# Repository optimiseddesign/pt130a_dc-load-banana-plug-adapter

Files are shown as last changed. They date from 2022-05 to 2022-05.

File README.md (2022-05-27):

# Release Notes

This document gives information and history for the following PCB release:

|Item |Value |
|---|---|
|Board Name |DC Load Banana Plug Adapter |
|PCB ID |PT130A |
|Revision (Layout/PCB) |1.0 |
|Revision (Schematic/BOM) |1A |
|Release Date |2022-05-27 |
|Customer |Internal |

> Note: This PCB release has been designed by Optimised Product Design Ltd, on behalf of the Customer Company.

## PCB Images

Top View:

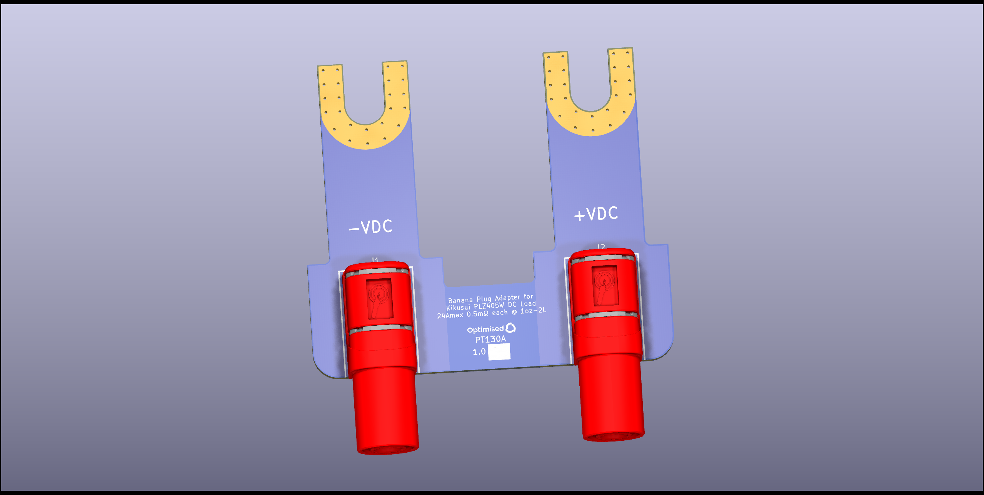
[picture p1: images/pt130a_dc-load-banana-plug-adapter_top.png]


Bottom View:

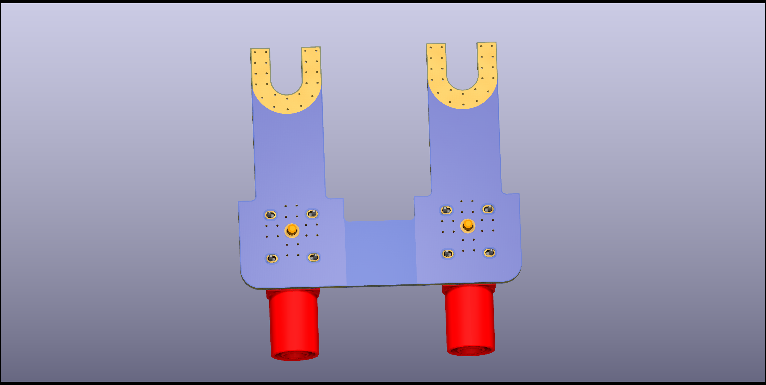
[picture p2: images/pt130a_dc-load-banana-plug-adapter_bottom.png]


[image_top]: images/pt130a_dc-load-banana-plug-adapter_top.png "Top View"
[image_bottom]: images/pt130a_dc-load-banana-plug-adapter_bottom.png "Bottom View"

## PCB Description

Adapter board for Kikusui 5W series DC Electronic Load (or similar, designed for PLZ405W).
Adapts screw terminals to shrouded sockets for 4mm Banana Plugs
24A Max, using 2-layer 1oz PCB

## Release History

```
Kevin Bibby / Optimised Product Design Ltd
PT130A 1.0 1A
27/05/2022
-------------
First release, for prototype manufacture
```

## PCB TO-DO List

The following items are to be done in future for this PCB:

**Major**
- Item

**Minor**
- Item

## Links

- [Kevin Bibby / Optimised Product Design Ltd]( http://www.optimiseddesign.com )

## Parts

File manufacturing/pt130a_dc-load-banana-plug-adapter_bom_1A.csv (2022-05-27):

Component | References | Quantity Per PCB | FitPart | Value | Description | Manufacturer1 | MPN1 | Manufacturer2 | MPN2 | Vendor1 | SKU1 | Vendor2 | SKU2
1 | J2 | 1 |  | SWEB 8094 AU / RT | RED Banana Test Connector, Jack, PCB Mount, 24 A, 1 kV | Schutzinger | SWEB 8094 AU / RT |  |  | Farnell | 3224813
2 | J1 | 1 |  | SWEB 8094 AU / SW | BLACK Banana Test Connector, Jack, PCB Mount, 24 A, 1 kV | Schutzinger | SWEB 8094 AU / SW |  |  | Farnell | 3224814
3 | LOGO1 | 1 | DNF | Optimised Logo | PCB Logo Virtual Part | N/A | N/A
Component Groups: | 3
Component Count: | 3
Fitted Components: | 2
Number of PCBs: | 1
Total components: | 2
Schematic Version: | 1A
Schematic Date: | 2022-05-27
PCB Variant: | default
BoM Date: | 2022-05-27 17:57:58
Schematic Source: | pt130a_dc-load-banana-plug-adapter.kicad_sch
KiCad Version: | Eeschema (6.0.1)

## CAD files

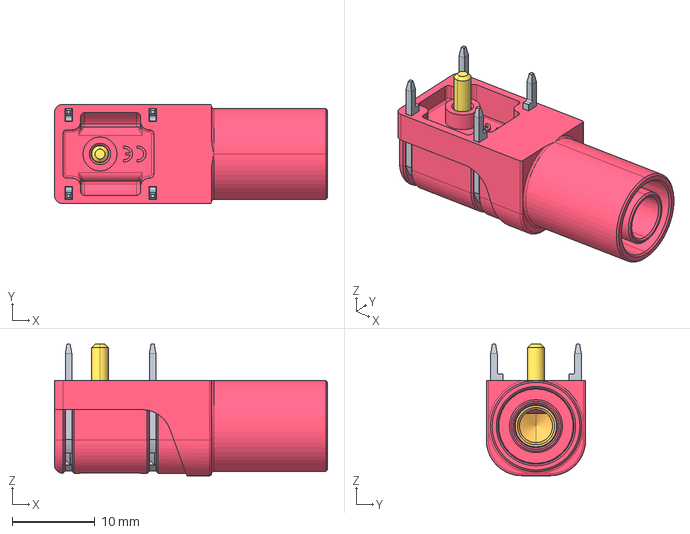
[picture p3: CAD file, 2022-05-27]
design/FCR7350R/sweb8094_8094_kunde.step
33.0 x 12.0 x 15.9 mm

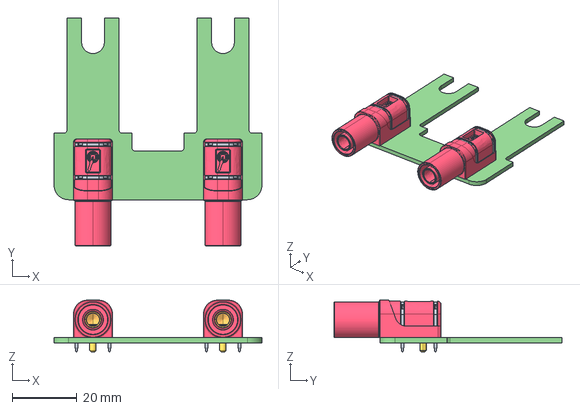
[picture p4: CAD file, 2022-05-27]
mechanical/pt130a_dc-load-banana-plug-adapter.step
64.0 x 70.3 x 15.9 mm
pt130a_dc-load-banana-plug-adapter PCB

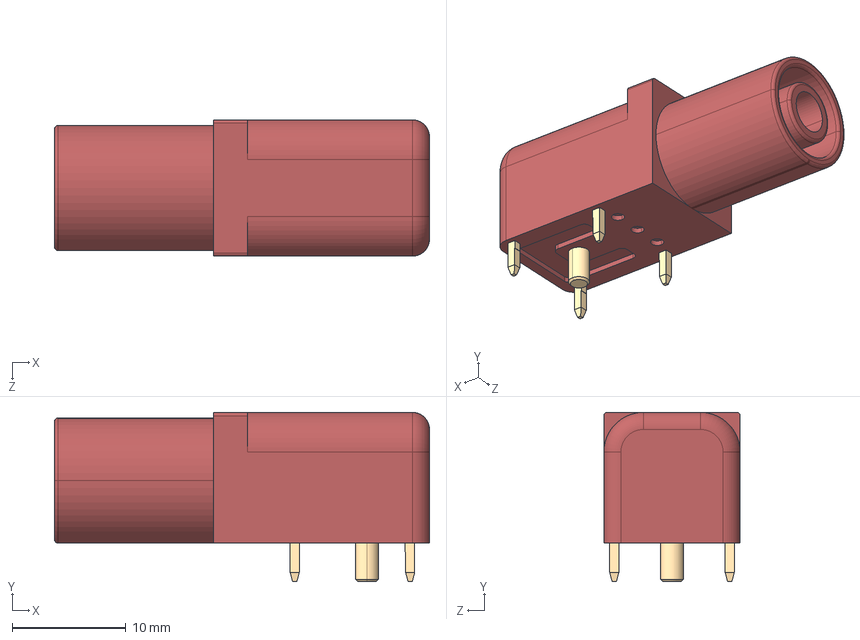
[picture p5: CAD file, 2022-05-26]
design/FCR7350R/FCR7350R.step
33.0 x 14.9 x 12.0 mm

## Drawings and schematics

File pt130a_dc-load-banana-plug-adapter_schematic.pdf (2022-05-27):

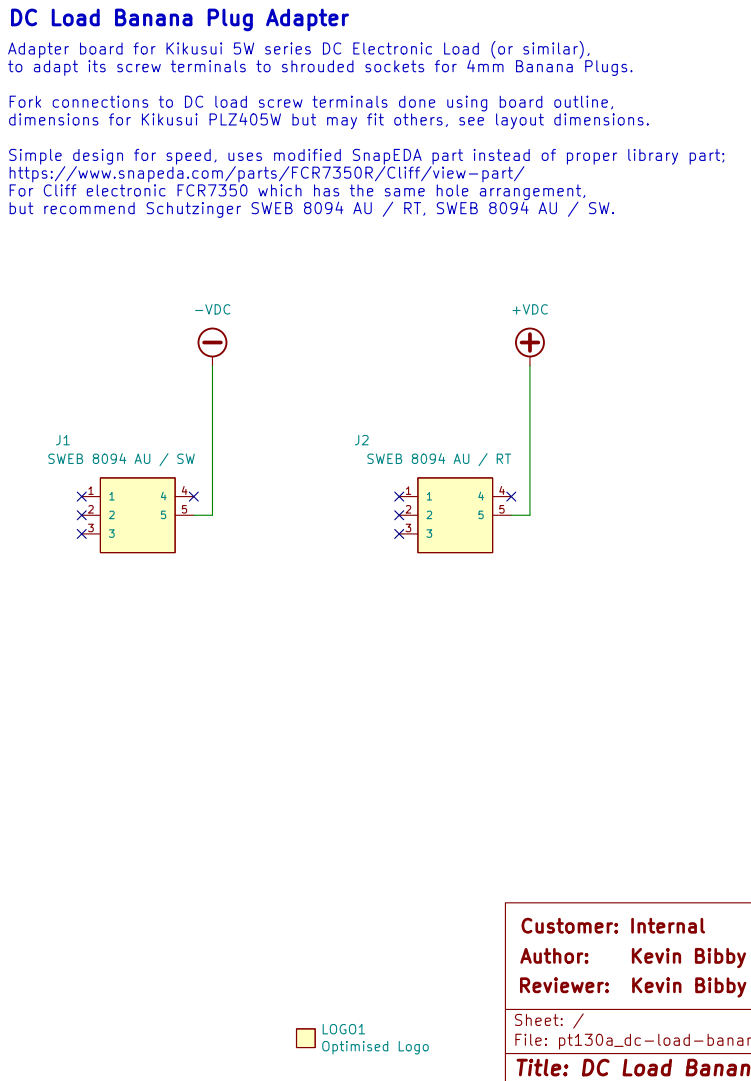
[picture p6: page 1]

Adapter board for Kikusui 5W series DC Electronic Load (or similar),
to adapt its screw terminals to shrouded sockets for 4mm Banana Plugs.

Fork connections to DC load screw terminals done using board outline,
dimensions for Kikusui PLZ405W but may fit others, see layout dimensions.

Simple design for speed, uses modified SnapEDA part instead of proper library part;
https://www.snapeda.com/parts/FCR7350R/Cliff/view-part/
For Cliff electronic FCR7350 which has the same hole arrangement,
but recommend Schutzinger SWEB 8094 AU / RT, SWEB 8094 AU / SW.

File: pt130a_dc-load-banana-plug-adapter.kicad_sch Sheet: / Author: Kevin Bibby
www.optimiseddesign.com Reviewer: Kevin Bibby

Copyright 2022 | PCB ID: PT130A Sheet: 1 of 1 Title: DC Load Banana Plug Adapter | D Date: 2022-05-27 KiCad E.D.A. kicad (6.0.1)

Size: A4 | Rev: 1A

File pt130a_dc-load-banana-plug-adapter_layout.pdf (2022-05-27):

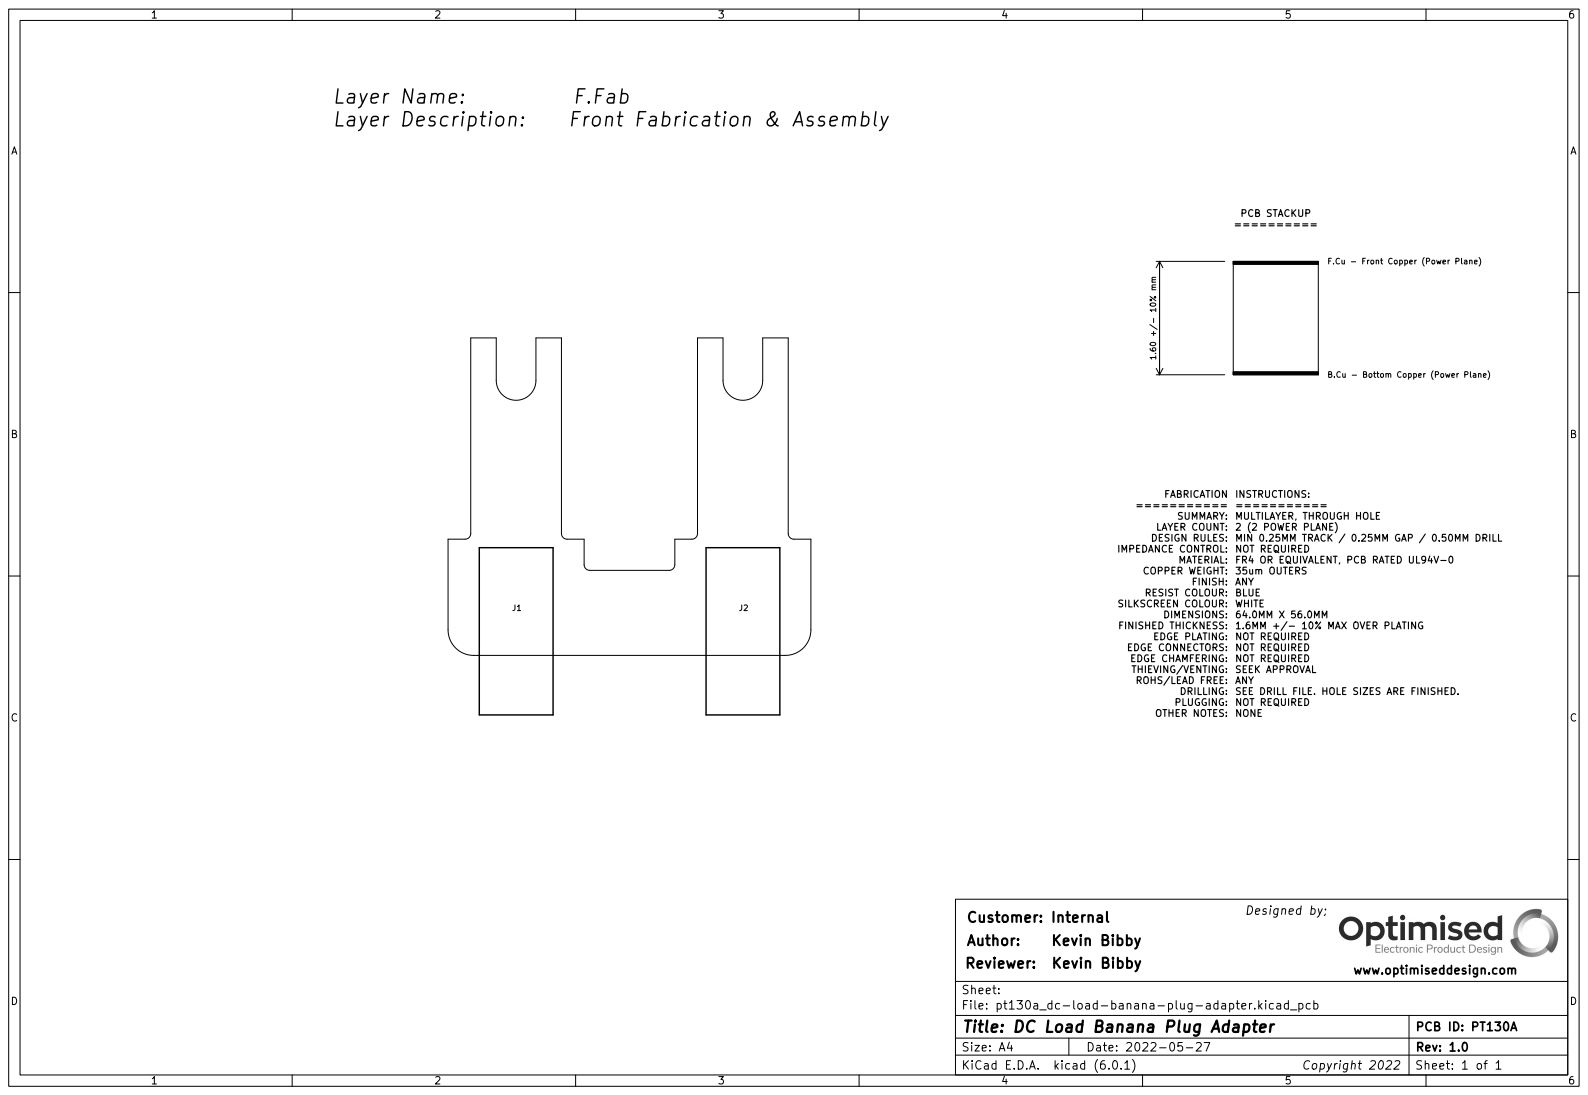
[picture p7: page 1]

Layer Description: Front Fabrication & Assembly

FABRICATION
=========== SUMMARY: LAYER COUNT: DESIGN RULES:

INSTRUCTIONS: =========== MULTILAYER, THROUGH HOLE

2 (2 POWER PLANE) MIN 0.25MM TRACK / 0.25MM GAP / 0.50MM DRILL NOT REQUIRED

IMPEDANCE CONTROL: MATERIAL: COPPER WEIGHT: FINISH: RESIST COLOUR: SILKSCREEN COLOUR: DIMENSIONS: FINISHED THICKNESS: EDGE PLATING: EDGE CONNECTORS: EDGE CHAMFERING: THIEVING/VENTING: ROHS/LEAD FREE: DRILLING: PLUGGING: OTHER NOTES:

FR4 OR EQUIVALENT, PCB RATED UL94V-0
35um OUTERS ANY BLUE WHITE

SEE DRILL FILE. HOLE SIZES ARE FINISHED. NOT REQUIRED

File: pt130a_dc-load-banana-plug-adapter.kicad_pcb Sheet: Author: Kevin Bibby
www.optimiseddesign.com Reviewer: Kevin Bibby

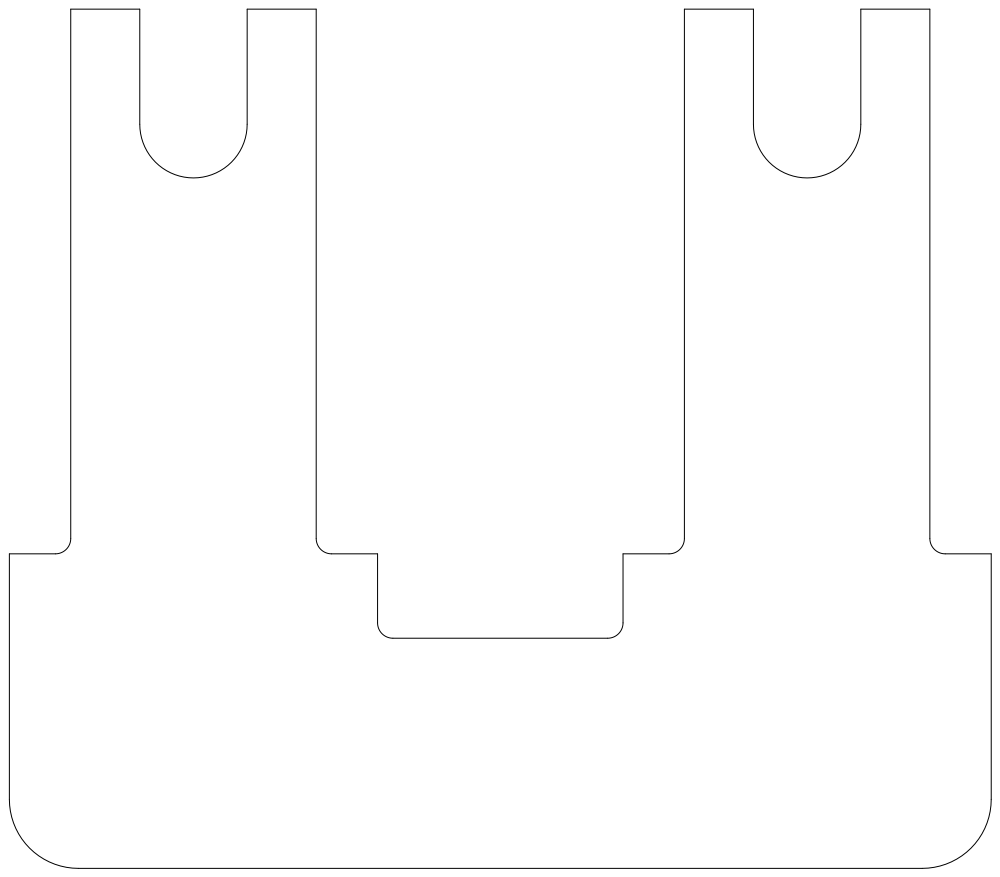
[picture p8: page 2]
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

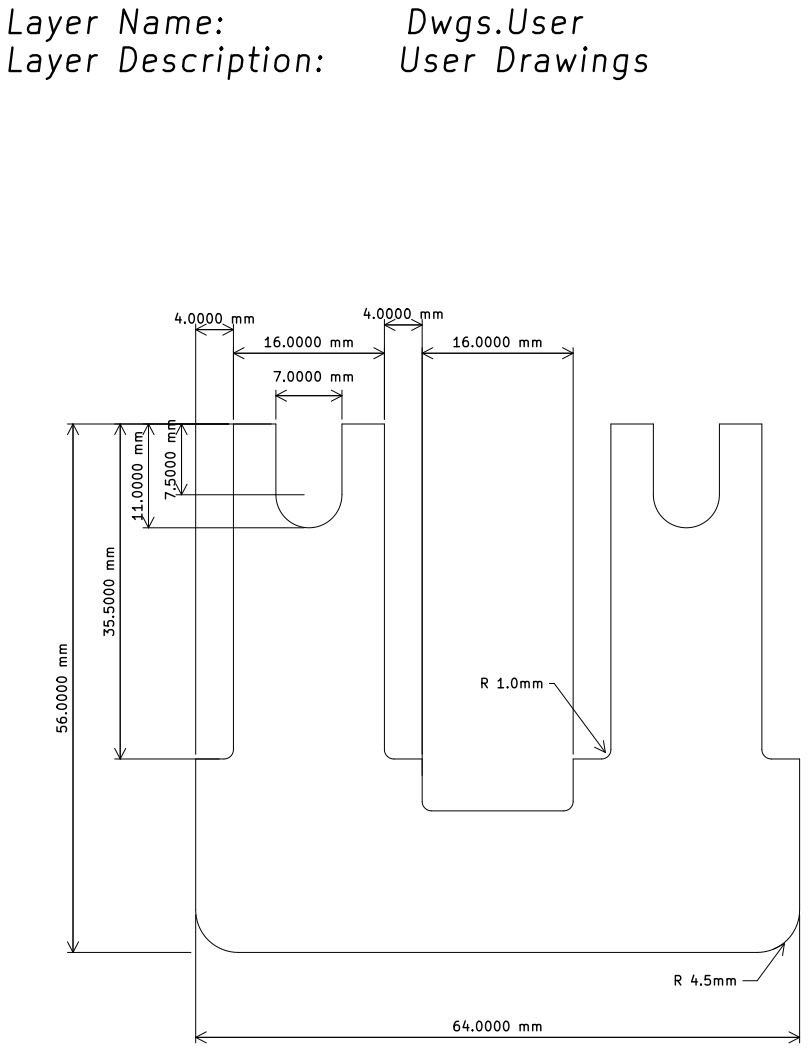
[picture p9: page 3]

Layer Description: User Drawings

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

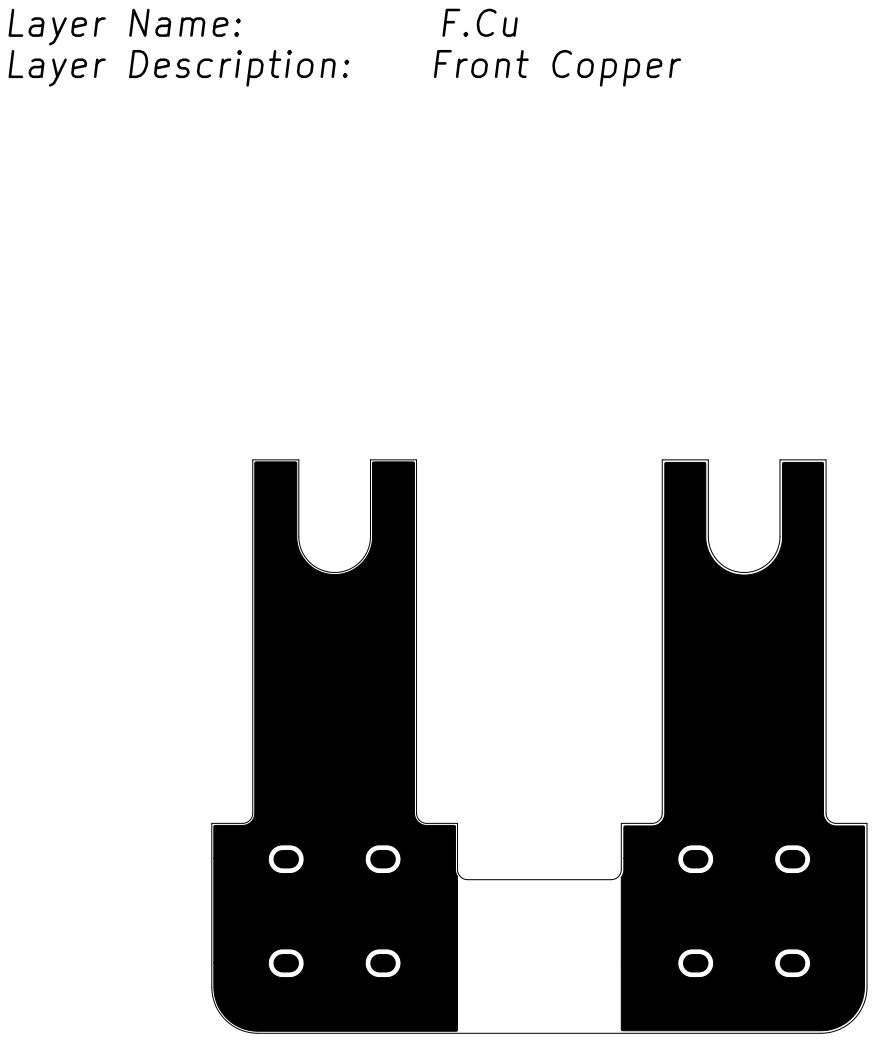
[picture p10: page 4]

Layer Description: Front Copper

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

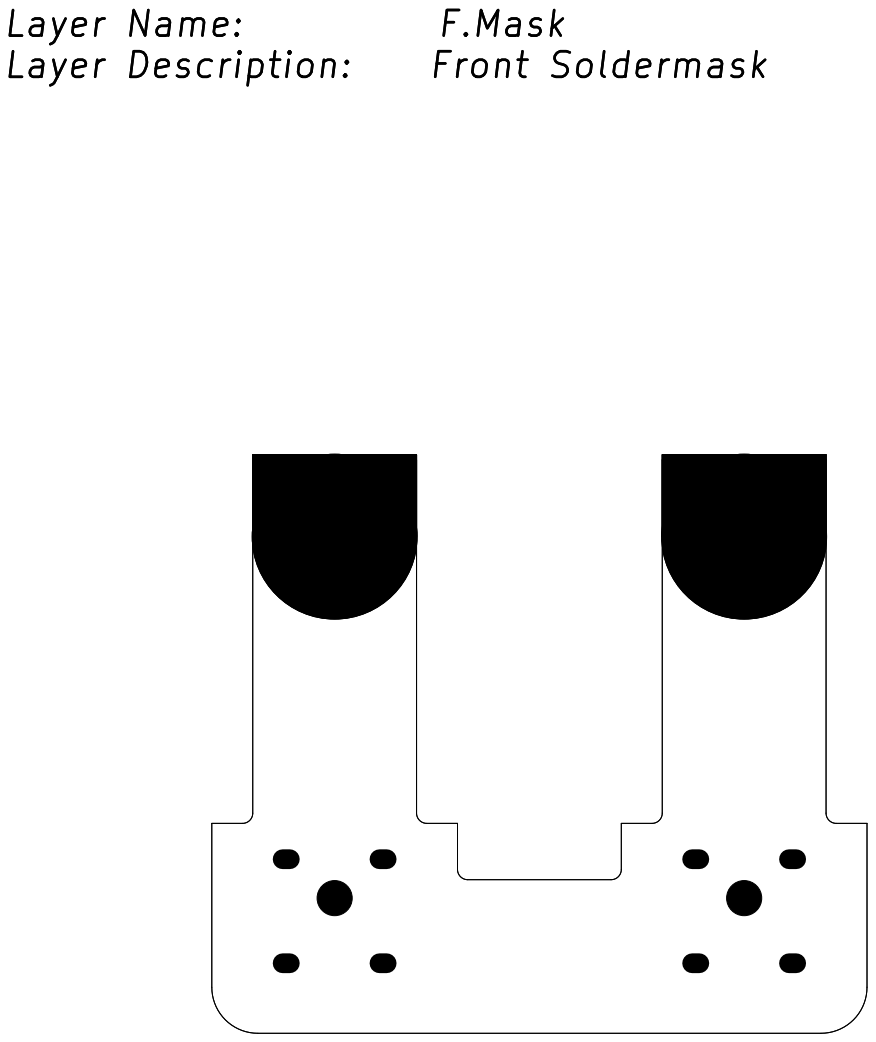
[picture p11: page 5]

Layer Description: Front Soldermask

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

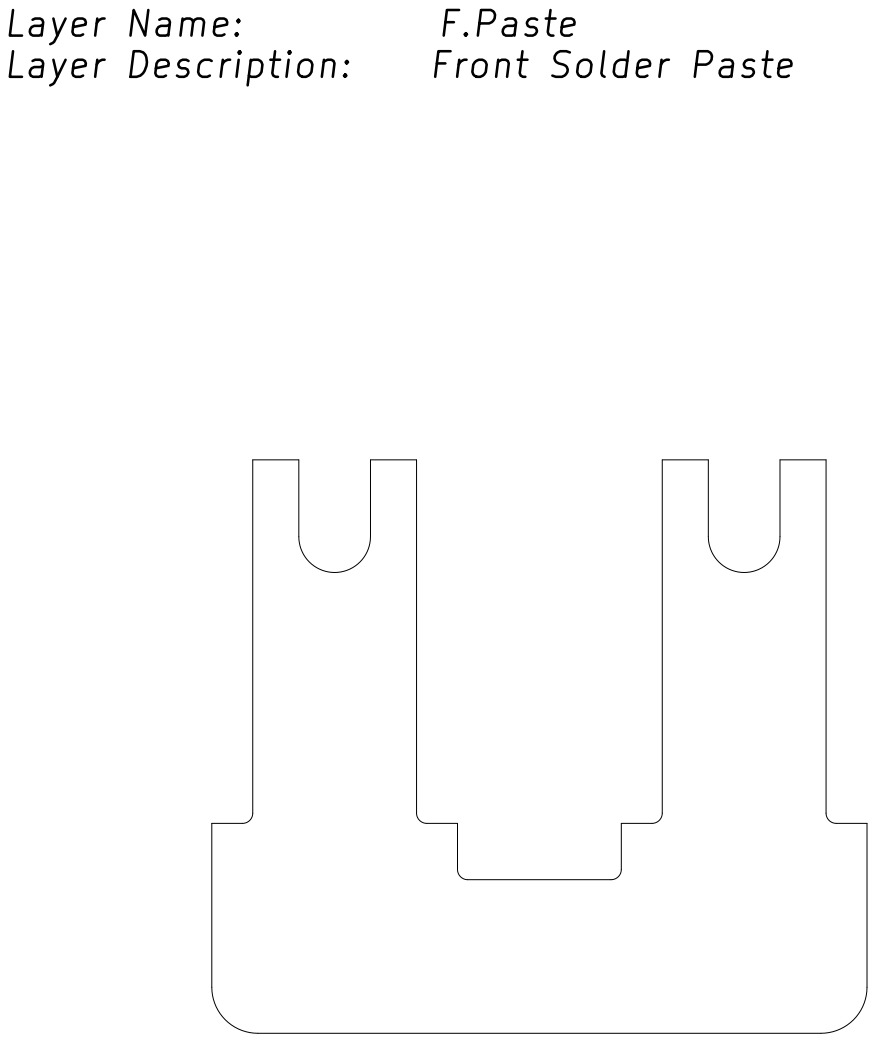
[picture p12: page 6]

Layer Description: Front Solder Paste

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

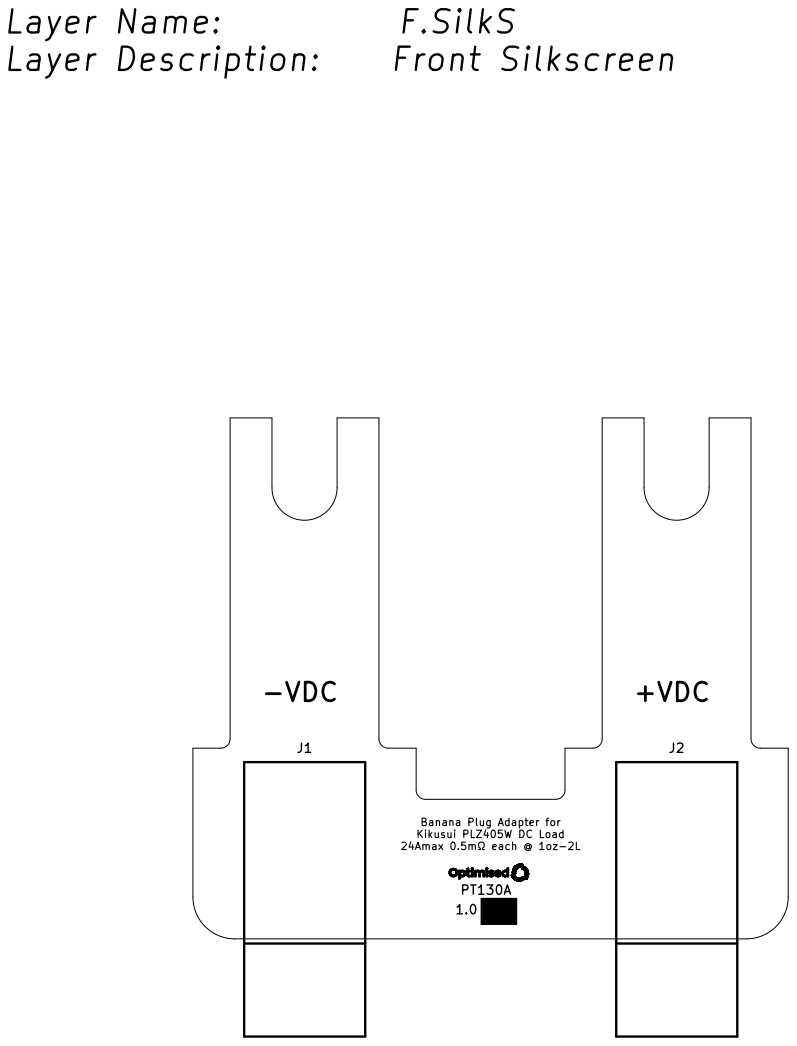
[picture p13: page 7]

Layer Description: Front Silkscreen

Banana Plug Adapter for Kikusui PLZ405W DC Load

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

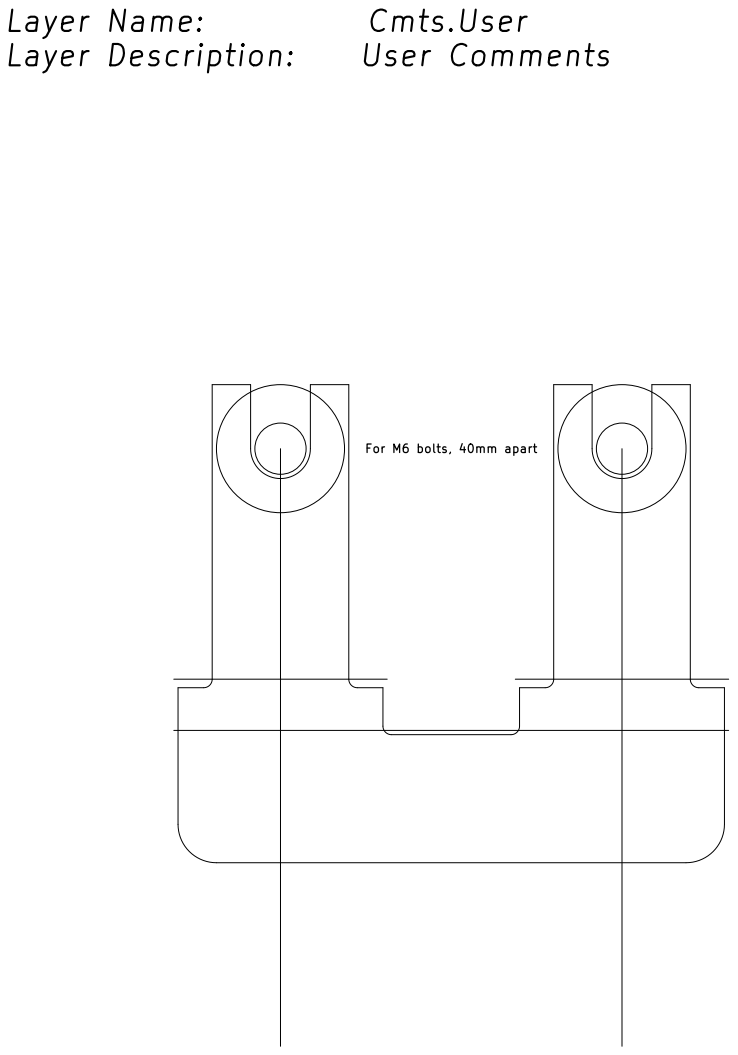
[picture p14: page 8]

Layer Description: User Comments

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

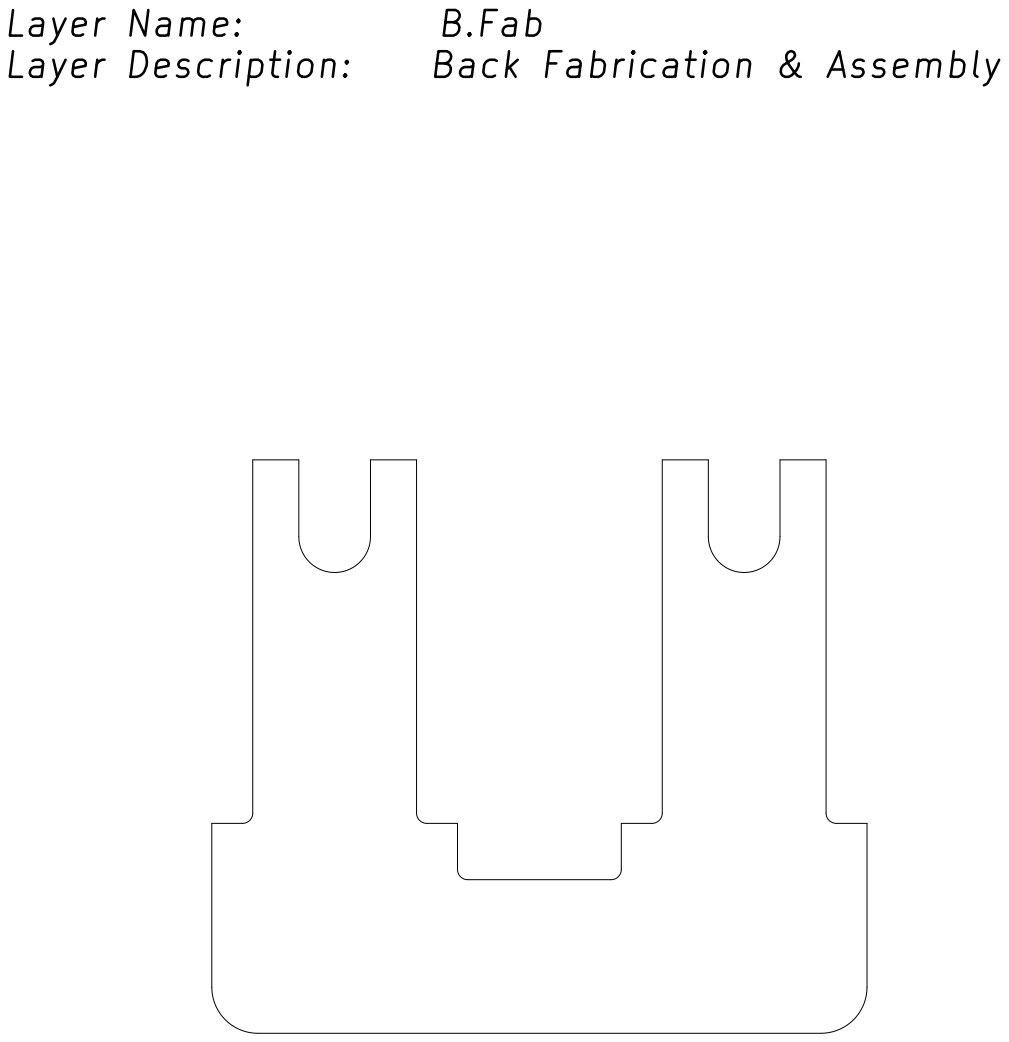
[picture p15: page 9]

Layer Description: Back Fabrication & Assembly

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

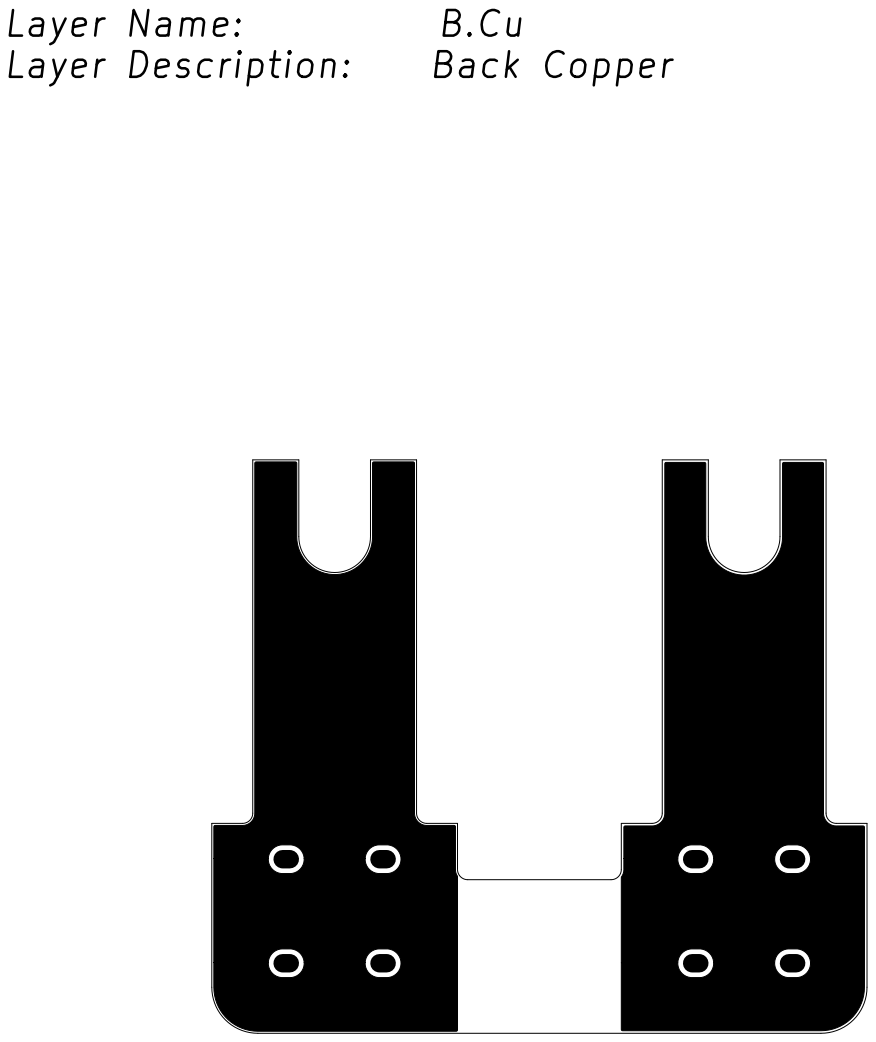
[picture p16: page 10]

Layer Description: Back Copper

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

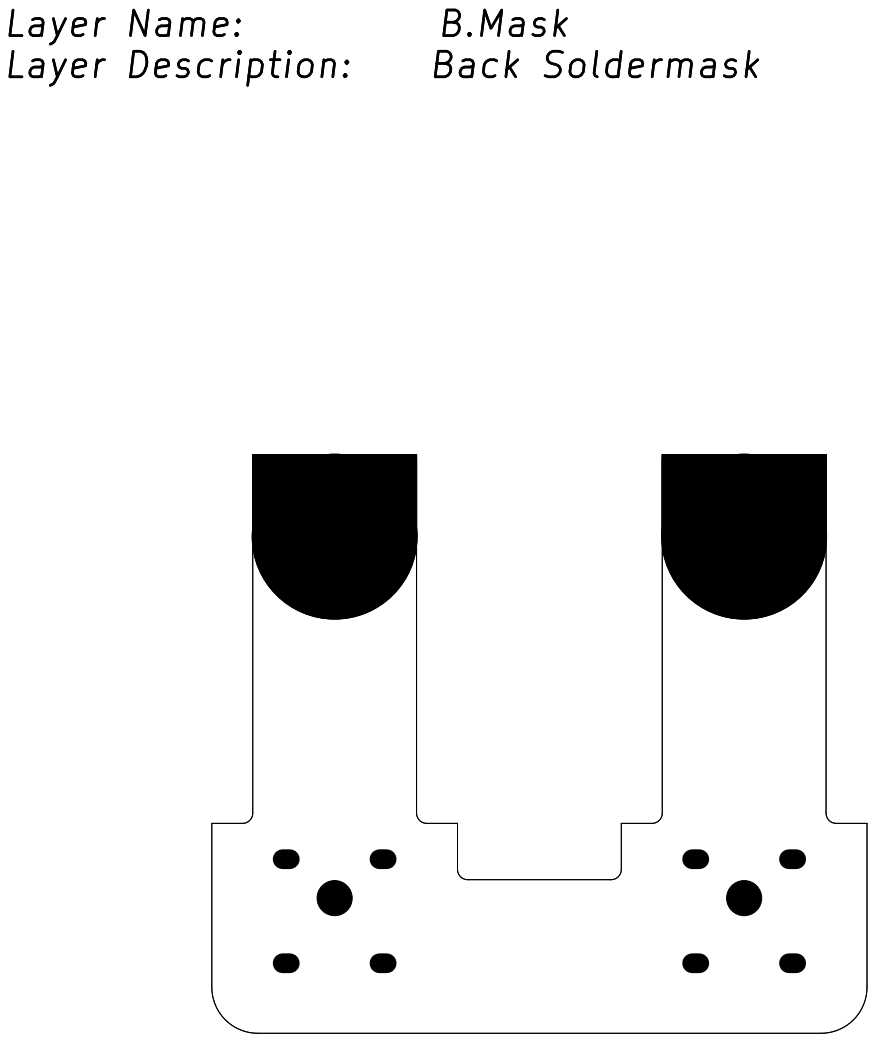
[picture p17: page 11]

Layer Description: Back Soldermask

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


Layer Description: Back Solder Paste

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


Layer Description: Back Silkscreen

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

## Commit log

2022-05-26 renamed kicad files for pt130a_dc-load-banana-plug-adapter customised readme file, deleted template readme
    [pt130a_dc-load-banana-plug-adapter.kicad_pcb, pt130a_dc-load-banana-plug-adapter.kicad_sch]
2022-05-26 setup titleblocks for PT128A deleted simulation folder, not needed
    [pt130a_dc-load-banana-plug-adapter.kicad_pcb, pt130a_dc-load-banana-plug-adapter.kicad_sch]
2022-05-26 added FCR7350R part locally, downloaded from snapeda... ...updated to kicad v6 format added descriptive schematic text deleted H1-H4, FID1-FID6 etc not needed
    [FCR7350R.step, pt130a_dc-load-banana-plug-adapter.kicad_sch]
2022-05-26 some verrrry basic adjustments to FCR7350 library part... ...removed snapeda symbol fields ...proper body, centred, sensible pins etc ...added local footprint part library ...added STEP model, aligne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
2022-05-26 added J1 J2 banana socket parts imported into layout, set solid contact set planes for +VDC -VDC all layers
    [pt130a_dc-load-banana-plug-adapter.kicad_pcb, pt130a_dc-load-banana-plug-adapter.kicad_sch]
2022-05-26 done approx mechanical design added silkscreen footprint line for start of socket part
    [pt130a_dc-load-banana-plug-adapter.kicad_pcb, pt130a_dc-load-banana-plug-adapter.kicad_sch]
2022-05-26 moved drill/place origin to bottom left of PCB exported in-progress STEP model for 3D printing
    [pt130a_dc-load-banana-plug-adapter.kicad_pcb, pt130a_dc-load-banana-plug-adapter.step]
2022-05-27 increased J1 J2 footprint hole sizes and made oval... ...to fit initial lip on SWEB 8094 pins so it lays flat added SWEB 8094 as primary STEP model for this footprint updated footprint from library a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
    [pt130a_dc-load-banana-plug-adapter.kicad_pcb, pt130a_dc-load-banana-plug-adapter.kicad_sch, sweb8094_8094_kunde.step]
2022-05-27 improved GND plane clearances... ...changed global edge min clearance from 0.5mm to 0.2mm ...changed plane clearances from 0.4mm to 0.2mm ...added 'Mech' net class with 0.5mm and added to pins1-4 adj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
    [pt130a_dc-load-banana-plug-adapter.kicad_pcb]
2022-05-27 adjusted footprint silkscreen to be less stoopid... ...means footprint moved slightly relative to origin refreshed footprint in design added silkscreen description, moved VDC silk
    [pt130a_dc-load-banana-plug-adapter.kicad_pcb]
2022-05-27 updated titleblocks, schematic text, readme exported BOM and schematic PDF for PT130A 1.0 1A release
    [pt130a_dc-load-banana-plug-adapter.kicad_sch, pt130a_dc-load-banana-plug-adapter_bom_1A.csv, pt130a_dc-load-banana-plug-adapter_bom_1A.xlsx]
2022-05-27 re-imported to layout, checked & excluded all DRCs changed to 2-layer PCB changed to 0.25/0.25mm design rules adjusted F.Fab text to match design (incl. blue soldermask) added proper User.Drawings di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
    [pt130a_dc-load-banana-plug-adapter.kicad_pcb]
2022-05-27 exported 3D render images, 3D STEP model for PT130A 1.0 1A exported gerber, drill, position files exported layout PDF
    [pt130a_dc-load-banana-plug-adapter-B_Cu.gbr, pt130a_dc-load-banana-plug-adapter-B_Fab.gbr, pt130a_dc-load-banana-plug-adapter-B_Mask.gbr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]
